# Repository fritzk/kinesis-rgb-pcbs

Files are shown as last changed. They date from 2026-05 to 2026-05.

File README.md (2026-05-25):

# PCBs to add per-key RGB lighting to Kinesis Advantage

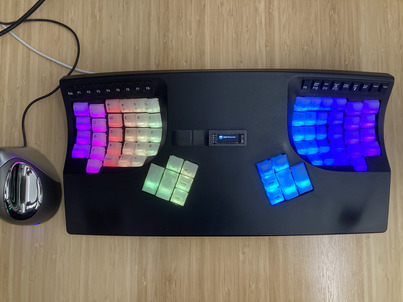
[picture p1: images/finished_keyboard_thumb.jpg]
Finished keyboard


# Attribution

Board outlines and starting schematics:

* [Pillz Mod](https://github.com/dcpedit/pillzmod) for main and thumb pcbs
* [kinesis-fn](https://github.com/bluelightning32/kinesis-fn) for function key pcbs

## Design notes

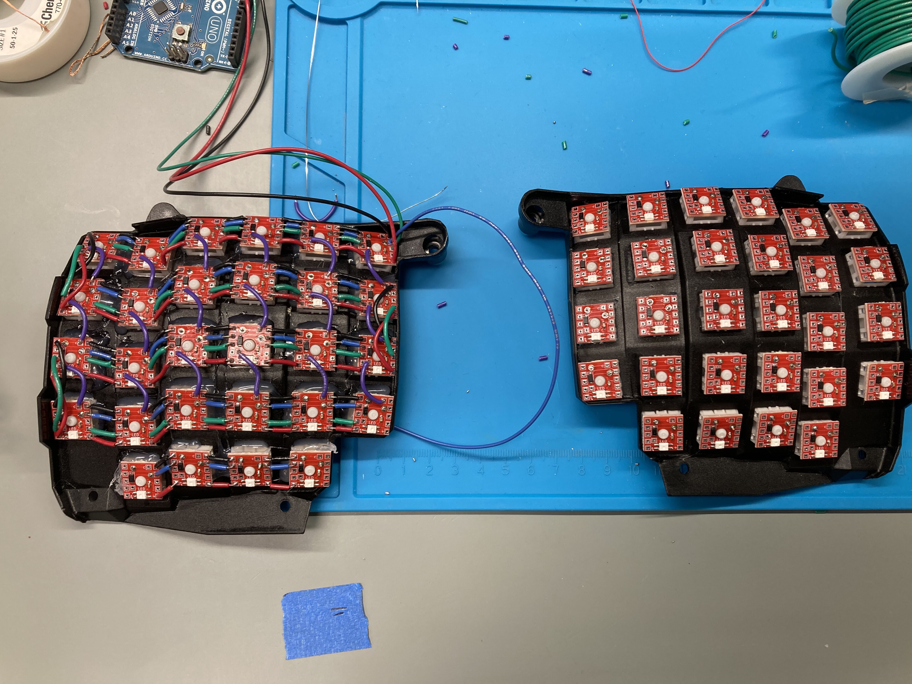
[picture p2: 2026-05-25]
key/img/key-pcb.jpg

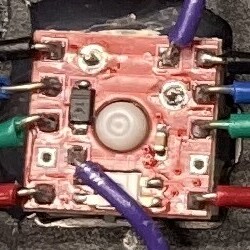
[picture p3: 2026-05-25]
key/img/key-pcb-cropped.jpg

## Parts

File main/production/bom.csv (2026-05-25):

Designator | Footprint | Quantity | Value | LCSC Part #
H1 | MountingHole_4.3mm_M4_Pad | 1 | mounting pad
J1, J2 | Molex_0039532135 | 2 | Conn_01x13
J10 | PinSocket_1x04_P2.54mm_Vertical | 1 | Conn_01x04
J3 | Molex_KK-254_AE-6410-06A_1x06_P2.54mm_Vertical | 1 | Conn_01x06
J4 | Molex_KK-254_AE-6410-06A_1x06_P2.54mm_Vertical | 1 | Conn_01x06_Pin
J5 | Molex_KK-254_AE-6410-09A_1x09_P2.54mm_Vertical | 1 | Conn_01x09
J6 | Molex_KK-254_AE-6410-09A_1x09_P2.54mm_Vertical | 1 | Conn_01x09_Pin
J7, J8 | PinHeader_1x10_P2.54mm_Vertical | 2 | Conn_01x10_Pin
J9 | PinHeader_1x01_P1.00mm_Vertical | 1 | Conn_01x01
M1 | MountingHole_6.4mm_M6 | 1 | MountingHole_6.4mm_M6
Q1 | SOT-23 | 1 | BSS138
R1, R2 | 0805 | 2 | 10K
U1 | ElitePi | 1 | Elite-Pi

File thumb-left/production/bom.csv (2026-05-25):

Designator | Footprint | Quantity | Value | LCSC Part #
C25, C35, C36, C46, C55, C56 | 0805 | 6 | 0.1 µF
D25, D35, D36, D46, D55, D56 | D_SOD-123F | 6 | 1N4148WL
J1 | PinHeader_1x10_P2.54mm_Vertical | 1 | Conn_01x10
LED25, LED35, LED36, LED46, LED55, LED56 | LED_MX_6028R | 6 | MX_SK6812MINI-E
MX25, MX35, MX55, MX56 | SW_Cherry_MX_PCB_1.00u | 4 | MX_SW_HS
MX36, MX46 | SW_Cherry_MX_PCB_2.00u_90deg | 2 | MX_SW_HS

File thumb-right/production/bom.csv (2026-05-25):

Designator | Footprint | Quantity | Value | LCSC Part #
C65, C66, C75, C85, C86, C96 | 0805 | 6 | 0.1 µF
D65, D66, D75, D85, D86, D96 | D_SOD-123F | 6 | 1N4148WL
J1 | PinHeader_1x10_P2.54mm_Vertical | 1 | Conn_01x10
LED65, LED66, LED75, LED85, LED86, LED96 | LED_MX_6028R | 6 | MX_SK6812MINI-E
MX65, MX75 | SW_Cherry_MX_PCB_2.00u_90deg | 2 | MX_SW_HS
MX66, MX85, MX86, MX96 | SW_Cherry_MX_PCB_1.00u | 4 | MX_SW_HS

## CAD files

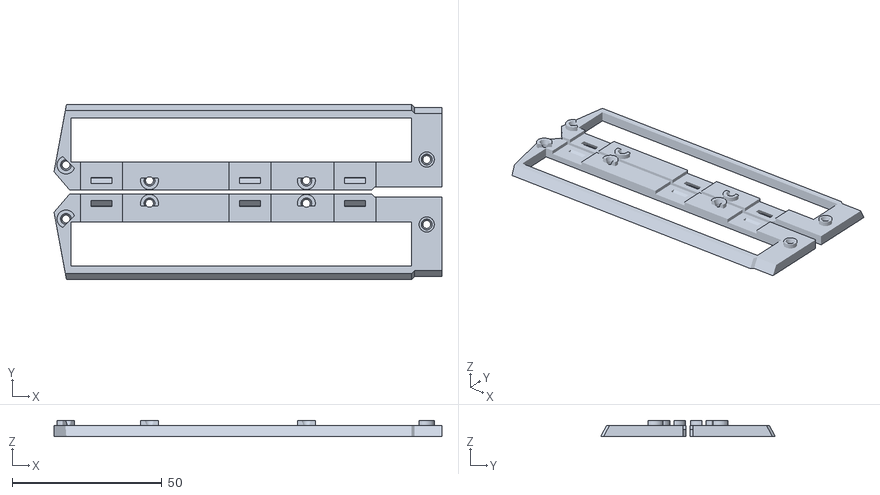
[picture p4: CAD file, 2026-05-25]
function/support.stl
129.6 x 58.4 x 5.50

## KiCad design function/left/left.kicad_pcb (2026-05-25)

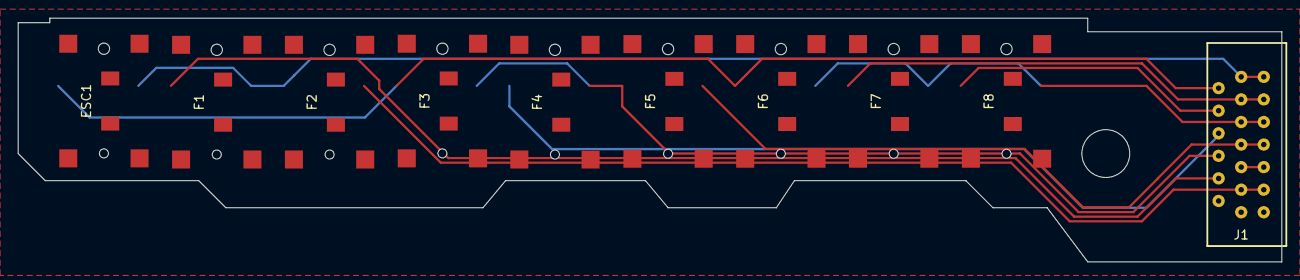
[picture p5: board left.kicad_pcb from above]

Board: 2 copper layers, 140.0 x 27.0 mm, 11 parts (0 on the bottom side), 12 nets.

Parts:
ESC1: PG1316M; SW_PG1316M
F1, F2, F3, F4, F5, F6, F7, F8: PG1316M; SW_PG1316M
H1: MountingHole_5.3mm_M5
J1: FFC_Connector_13P

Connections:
GND: J1.1, J1.1B
unnamed: ESC1.1, F3.1, F6.1, J1.12
unnamed: ESC1.2, F1.2, F2.1, J1.13, J1.13B
unnamed: F1.1, J1.4
unnamed: F2.2, J1.3, J1.3B
unnamed: F3.2, F4.2, F5.1, J1.6
unnamed: F4.1, J1.8
unnamed: F5.2, J1.7, J1.7B
unnamed: F6.2, F7.2, F8.2, J1.9, J1.9B
unnamed: F7.1, J1.11, J1.11B
unnamed: F8.1, J1.10
unnamed: J1.5, J1.5B

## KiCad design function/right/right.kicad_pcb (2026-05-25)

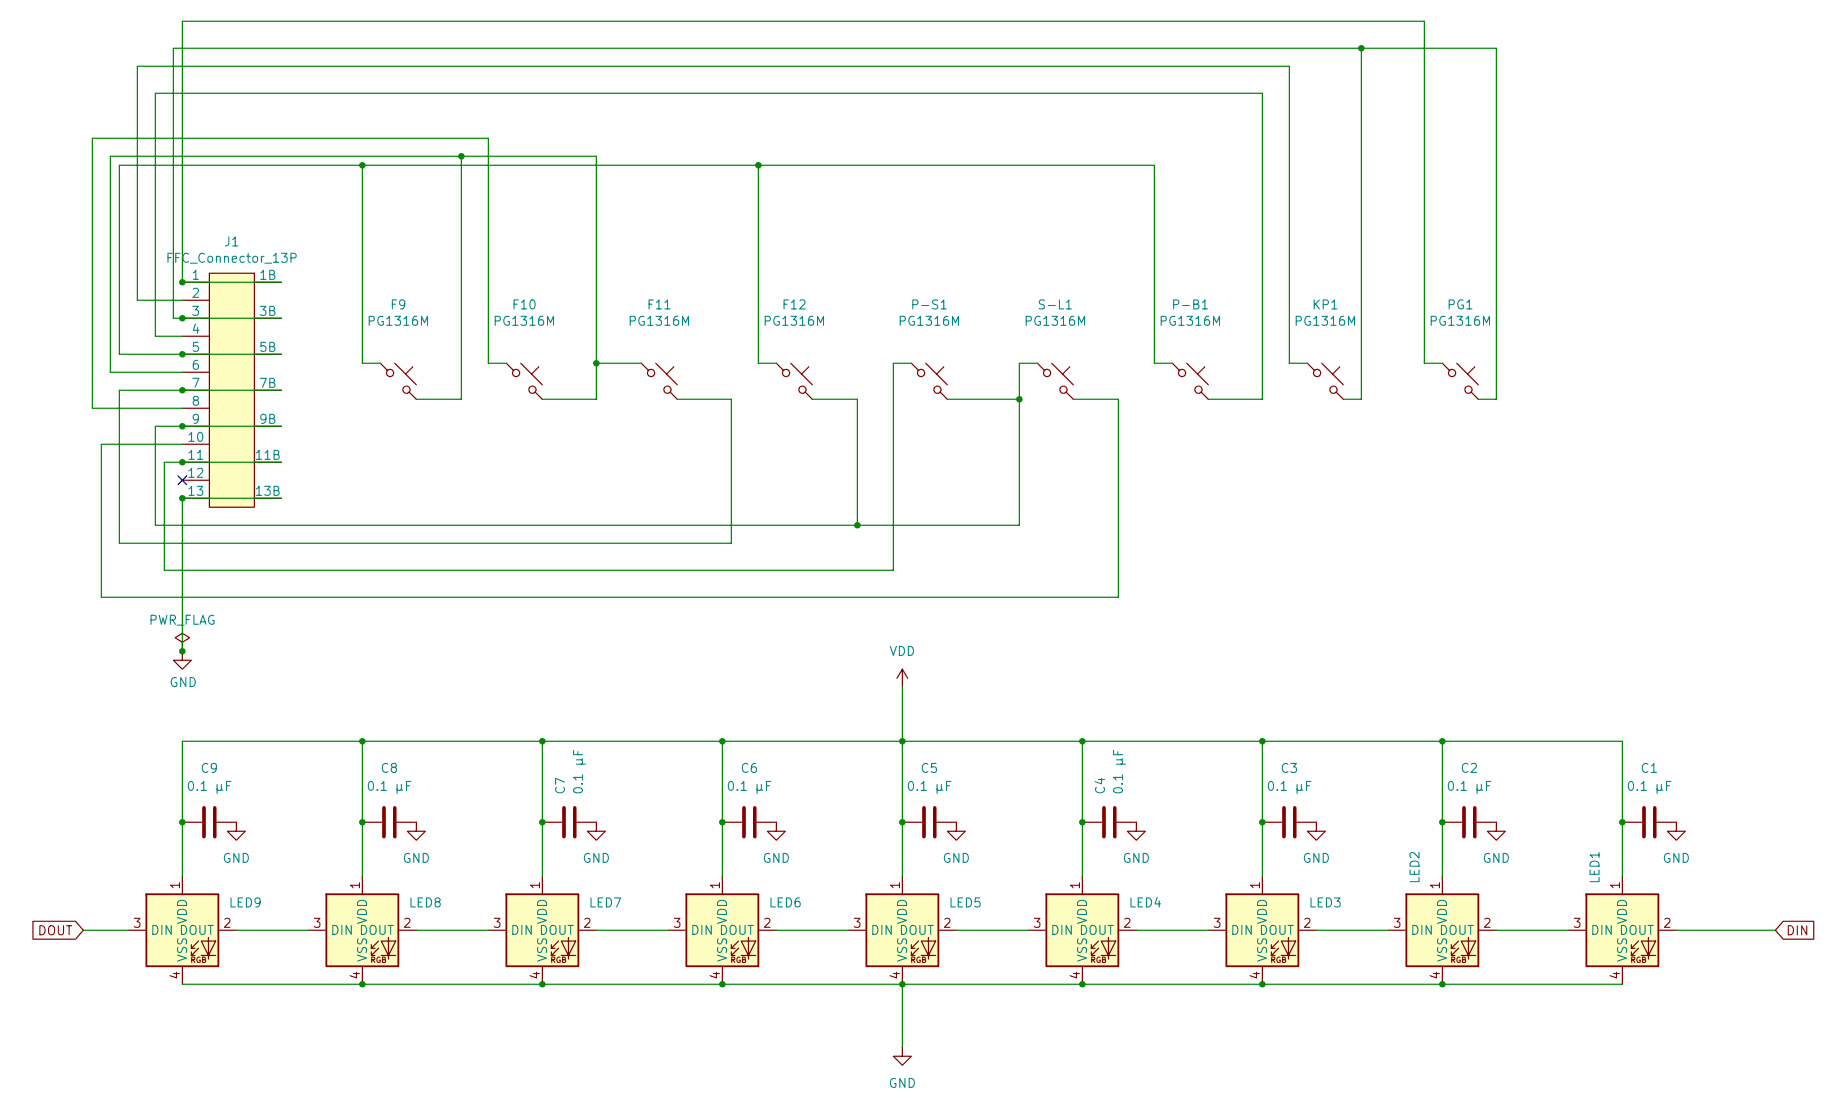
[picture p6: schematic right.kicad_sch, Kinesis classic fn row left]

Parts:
C1, C2, C3, C4, C5, C6, C7, C8, C9: 0.1 µF; C_0805_2012Metric_Pad1.18x1.45mm_HandSolder
F9, F10, F11, F12: PG1316M; SW_PG1316M
J1: FFC_Connector_13P
KP1: PG1316M; SW_PG1316M
LED1, LED2, LED3, LED4, LED5, LED6, LED7, LED8, LED9: MX_SK6812MINI-E; SK6812-MINI-E
P-B1: PG1316M; SW_PG1316M
P-S1: PG1316M; SW_PG1316M
PG1: PG1316M; SW_PG1316M
S-L1: PG1316M; SW_PG1316M

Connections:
DIN: LED1.2 (DOUT)
DOUT: LED9.3 (DIN)
GND: C1.2, C2.2, C3.2, C4.2, C5.2, C6.2, C7.2, C8.2, C9.2, J1.13, J1.13B, LED1.4 (VSS), LED2.4 (VSS), LED3.4 (VSS), LED4.4 (VSS), LED5.4 (VSS), LED6.4 (VSS), LED7.4 (VSS), LED8.4 (VSS), LED9.4 (VSS)
unnamed: F10.1, J1.8
unnamed: F9.2, F10.2, F11.1, J1.6
unnamed: F11.2, J1.7, J1.7B
unnamed: F9.1, F12.1, J1.5, J1.5B, P-B1.1
unnamed: F12.2, J1.9, J1.9B, P-S1.2, S-L1.1
unnamed: J1.1, J1.1B, PG1.1
unnamed: J1.2, KP1.1
unnamed: J1.3, J1.3B, KP1.2, PG1.2
unnamed: J1.4, P-B1.2
unnamed: J1.10, S-L1.2
unnamed: J1.11, J1.11B, P-S1.1
unnamed: LED1.3 (DIN), LED2.2 (DOUT)
unnamed: LED2.3 (DIN), LED3.2 (DOUT)
unnamed: LED3.3 (DIN), LED4.2 (DOUT)
unnamed: LED4.3 (DIN), LED5.2 (DOUT)
unnamed: LED5.3 (DIN), LED6.2 (DOUT)
unnamed: LED6.3 (DIN), LED7.2 (DOUT)
unnamed: LED7.3 (DIN), LED8.2 (DOUT)
unnamed: LED8.3 (DIN), LED9.2 (DOUT)
VDD: C1.1, C2.1, C3.1, C4.1, C5.1, C6.1, C7.1, C8.1, C9.1, LED1.1 (VDD), LED2.1 (VDD), LED3.1 (VDD), LED4.1 (VDD), LED5.1 (VDD), LED6.1 (VDD), LED7.1 (VDD), LED8.1 (VDD), LED9.1 (VDD)

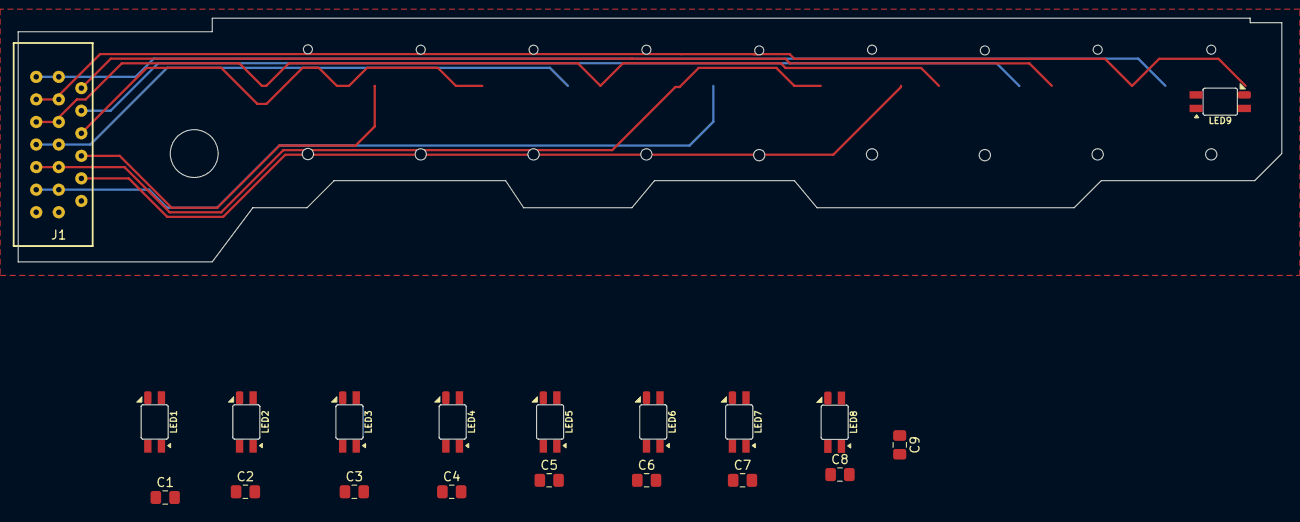
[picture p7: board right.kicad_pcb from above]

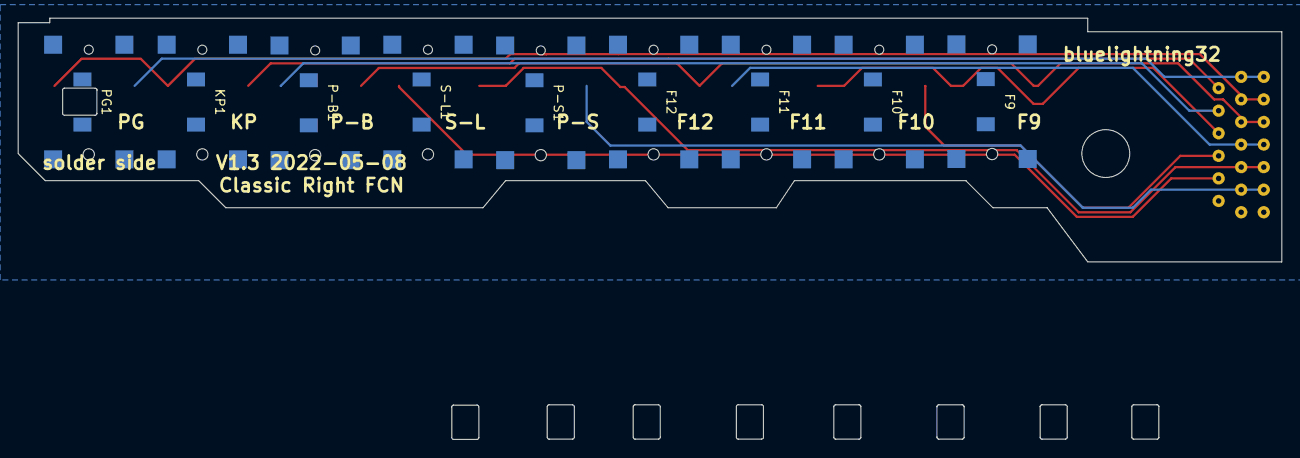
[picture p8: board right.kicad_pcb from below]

Board: 2 copper layers, 29 parts (9 on the bottom side), 21 nets.

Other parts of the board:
H1: MountingHole_5.3mm_M5

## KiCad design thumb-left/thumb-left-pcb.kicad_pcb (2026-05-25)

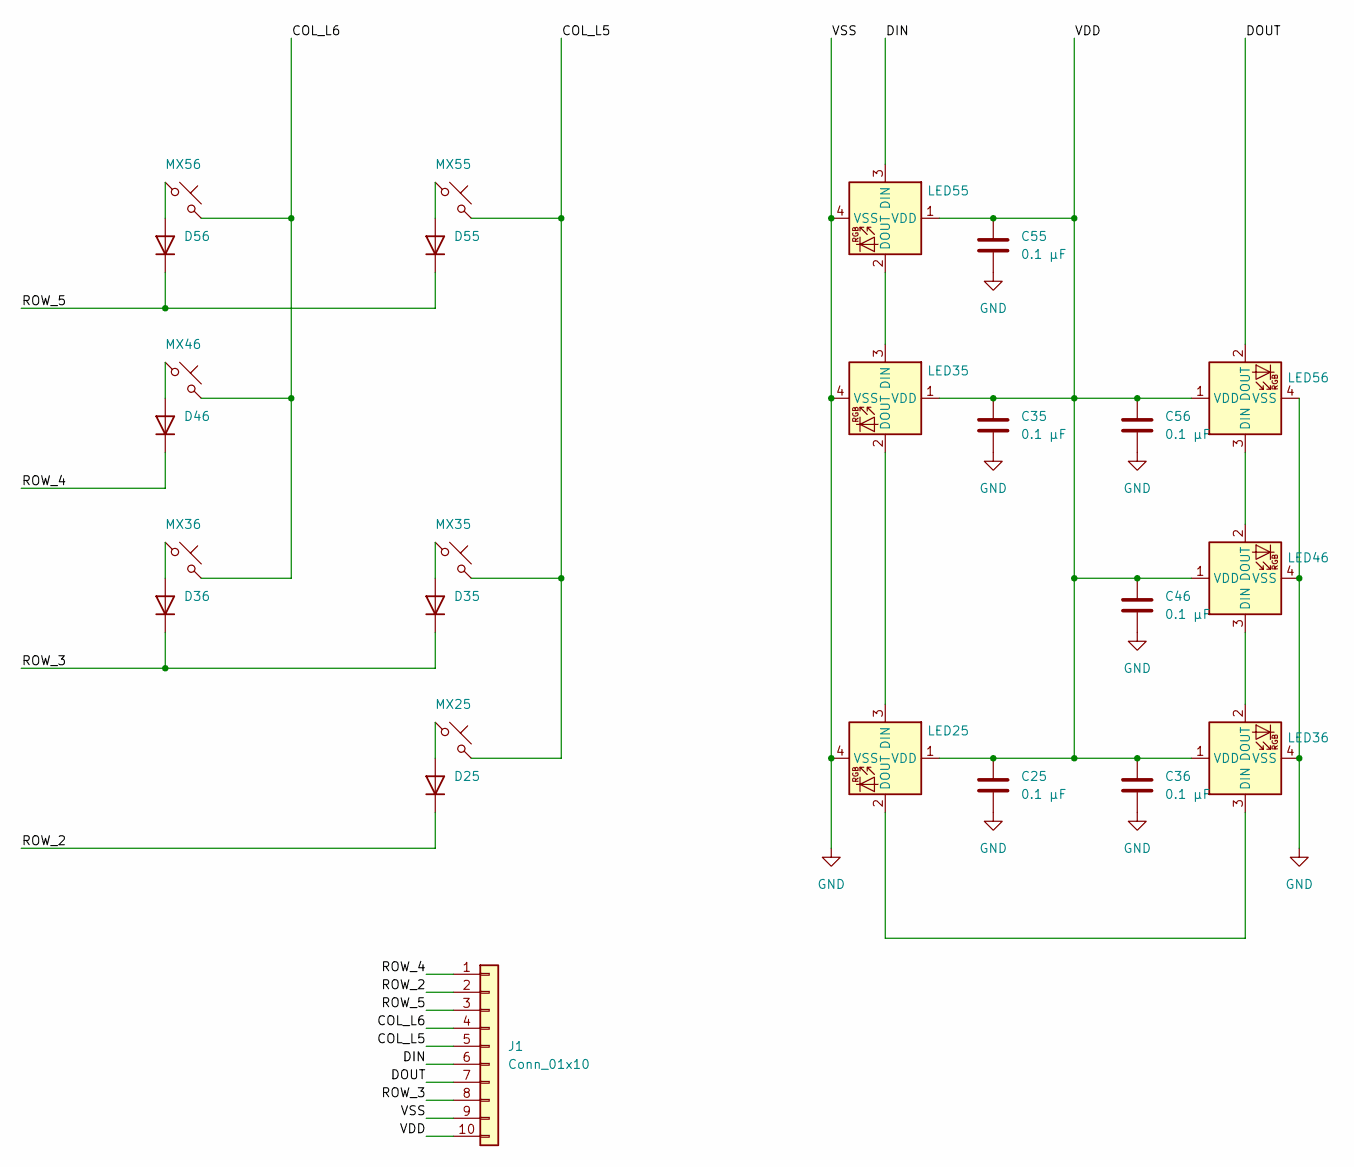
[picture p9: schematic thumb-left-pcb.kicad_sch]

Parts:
C25, C35, C36, C46, C55, C56: 0.1 µF; C_0805_2012Metric_Pad1.18x1.45mm_HandSolder
D25, D35, D36, D46, D55, D56: 1N4148WL; D_SOD-123F
J1: Conn_01x10; PinHeader_1x10_P2.54mm_Vertical
LED25, LED35, LED36, LED46, LED55, LED56: MX_SK6812MINI-E; LED_MX_6028R
MX25, MX35, MX55, MX56: MX_SW_HS; SW_Cherry_MX_PCB_1.00u
MX36, MX46: MX_SW_HS; SW_Cherry_MX_PCB_2.00u_90deg

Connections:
/COL_L5: J1.5, MX25.2, MX35.2, MX55.2
/COL_L6: J1.4, MX36.2, MX46.2, MX56.2
/DIN: J1.6, LED55.3 (DIN)
/DOUT: J1.7, LED56.2 (DOUT)
/ROW_2: D25.1 (K), J1.2
/ROW_3: D35.1 (K), D36.1 (K), J1.8
/ROW_4: D46.1 (K), J1.1
/ROW_5: D55.1 (K), D56.1 (K), J1.3
/VDD: C25.1, C35.1, C36.1, C46.1, C55.1, C56.1, J1.10, LED25.1 (VDD), LED35.1 (VDD), LED36.1 (VDD), LED46.1 (VDD), LED55.1 (VDD), LED56.1 (VDD)
GND: C25.2, C35.2, C36.2, C46.2, C55.2, C56.2, J1.9, LED25.4 (VSS), LED35.4 (VSS), LED36.4 (VSS), LED46.4 (VSS), LED55.4 (VSS), LED56.4 (VSS)
unnamed: D25.2 (A), MX25.1
unnamed: D35.2 (A), MX35.1
unnamed: D36.2 (A), MX36.1
unnamed: D46.2 (A), MX46.1
unnamed: D55.2 (A), MX55.1
unnamed: D56.2 (A), MX56.1
unnamed: LED25.3 (DIN), LED35.2 (DOUT)
unnamed: LED25.2 (DOUT), LED36.3 (DIN)
unnamed: LED35.3 (DIN), LED55.2 (DOUT)
unnamed: LED36.2 (DOUT), LED46.3 (DIN)
unnamed: LED46.2 (DOUT), LED56.3 (DIN)

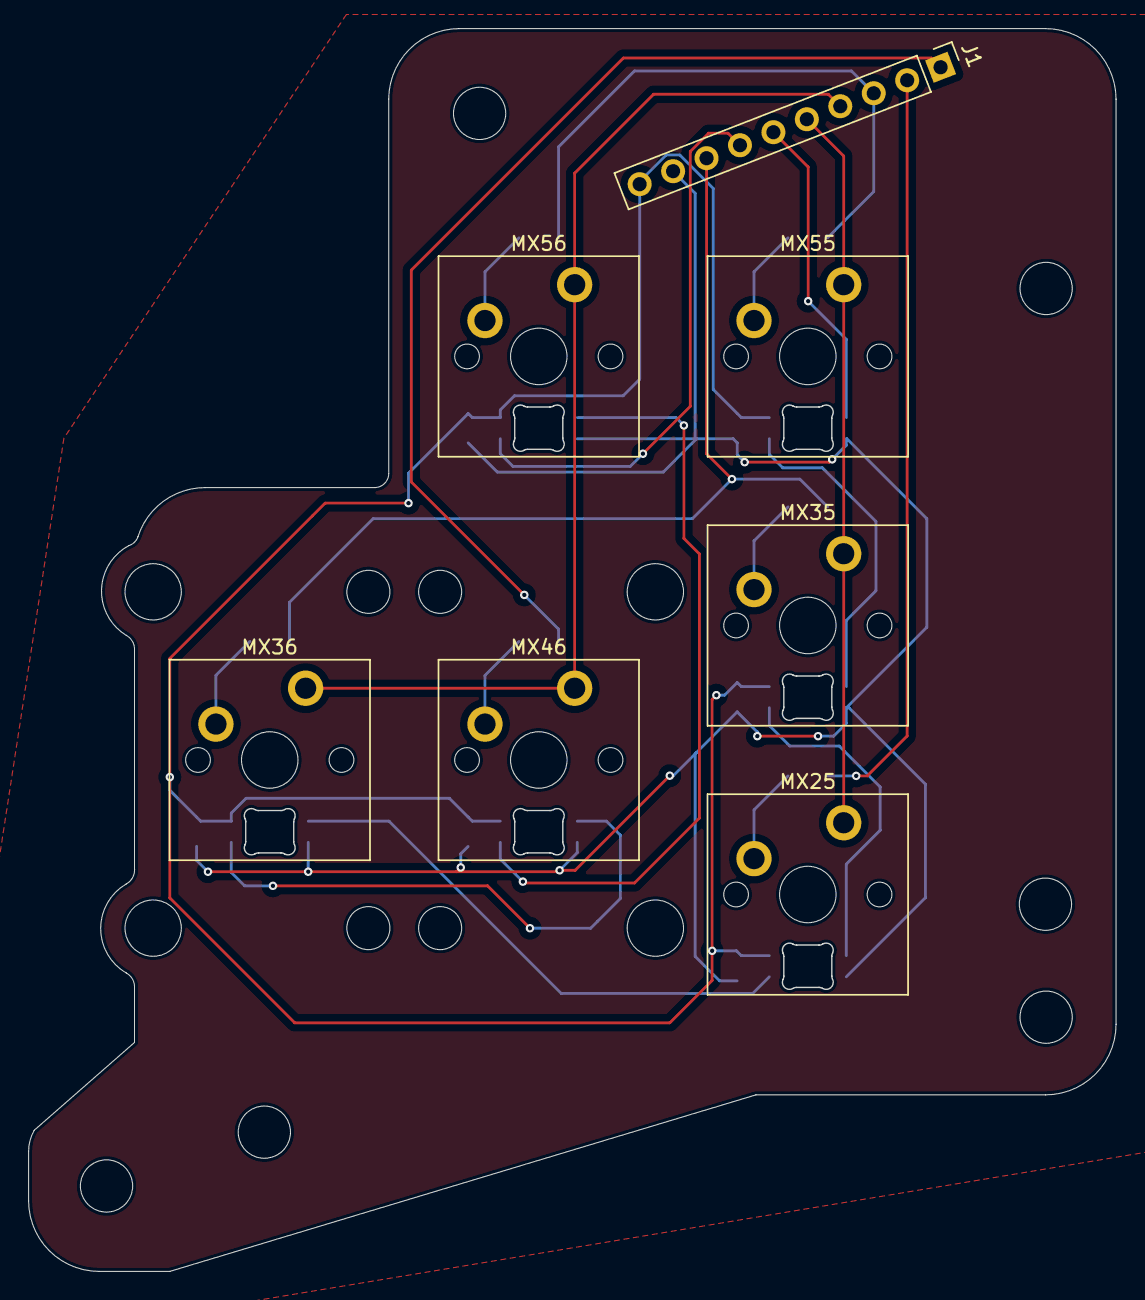
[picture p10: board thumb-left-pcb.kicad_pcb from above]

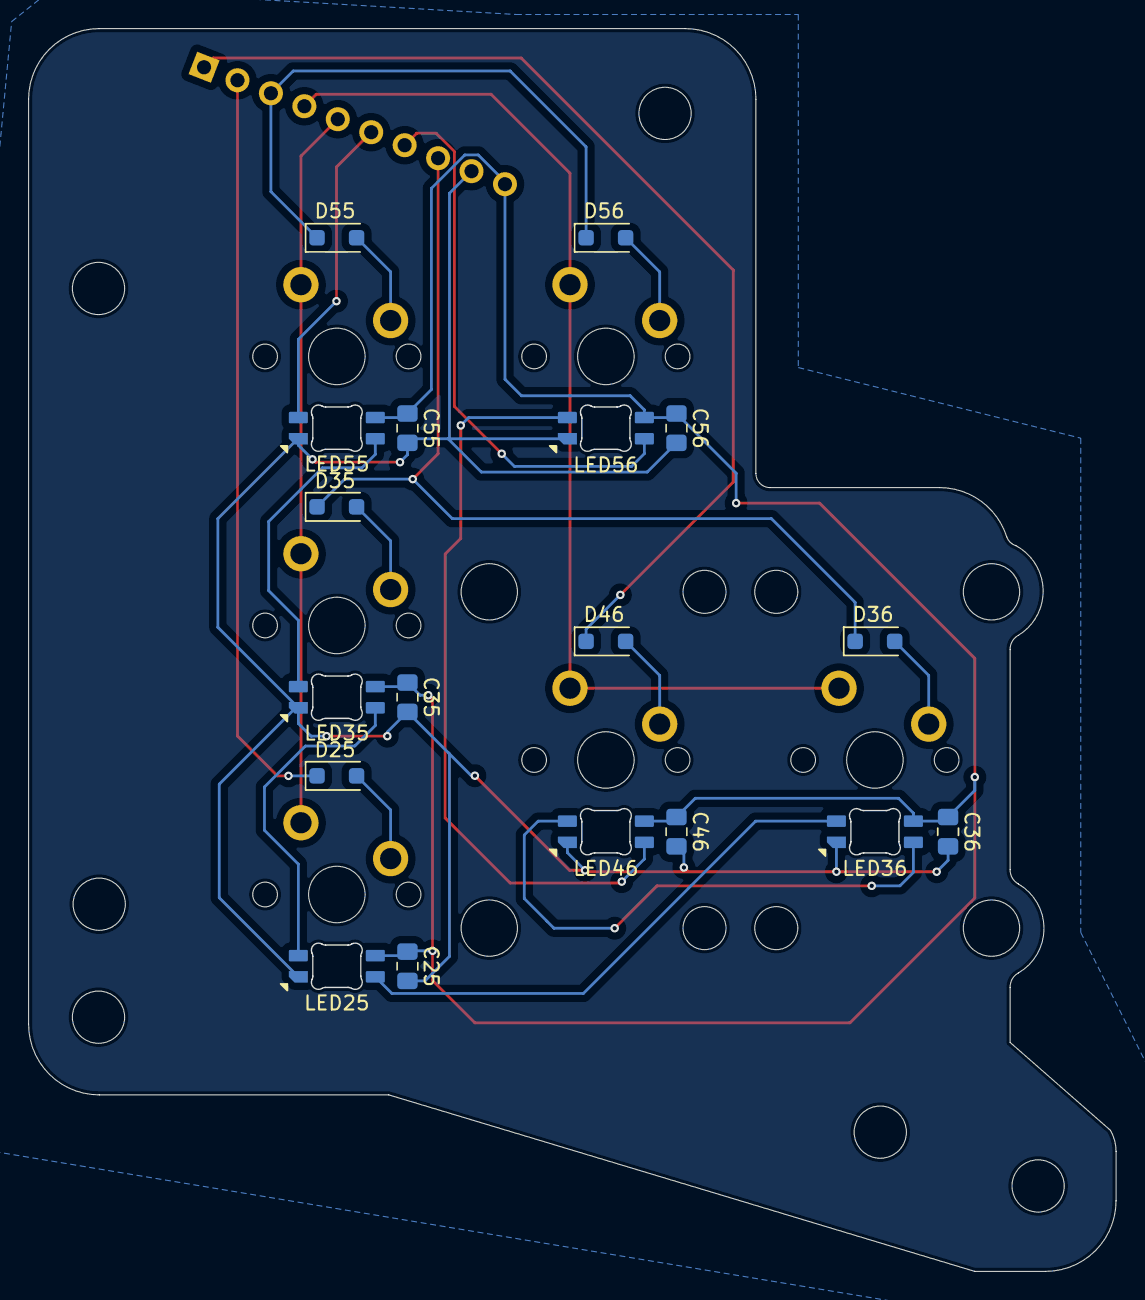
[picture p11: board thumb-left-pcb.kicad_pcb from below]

Board: 2 copper layers, 77.0 x 88.0 mm, 31 parts (18 on the bottom side), 21 nets.

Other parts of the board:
REF1, REF2, REF3, REF4, REF5, REF6: MountingHole_3.7mm

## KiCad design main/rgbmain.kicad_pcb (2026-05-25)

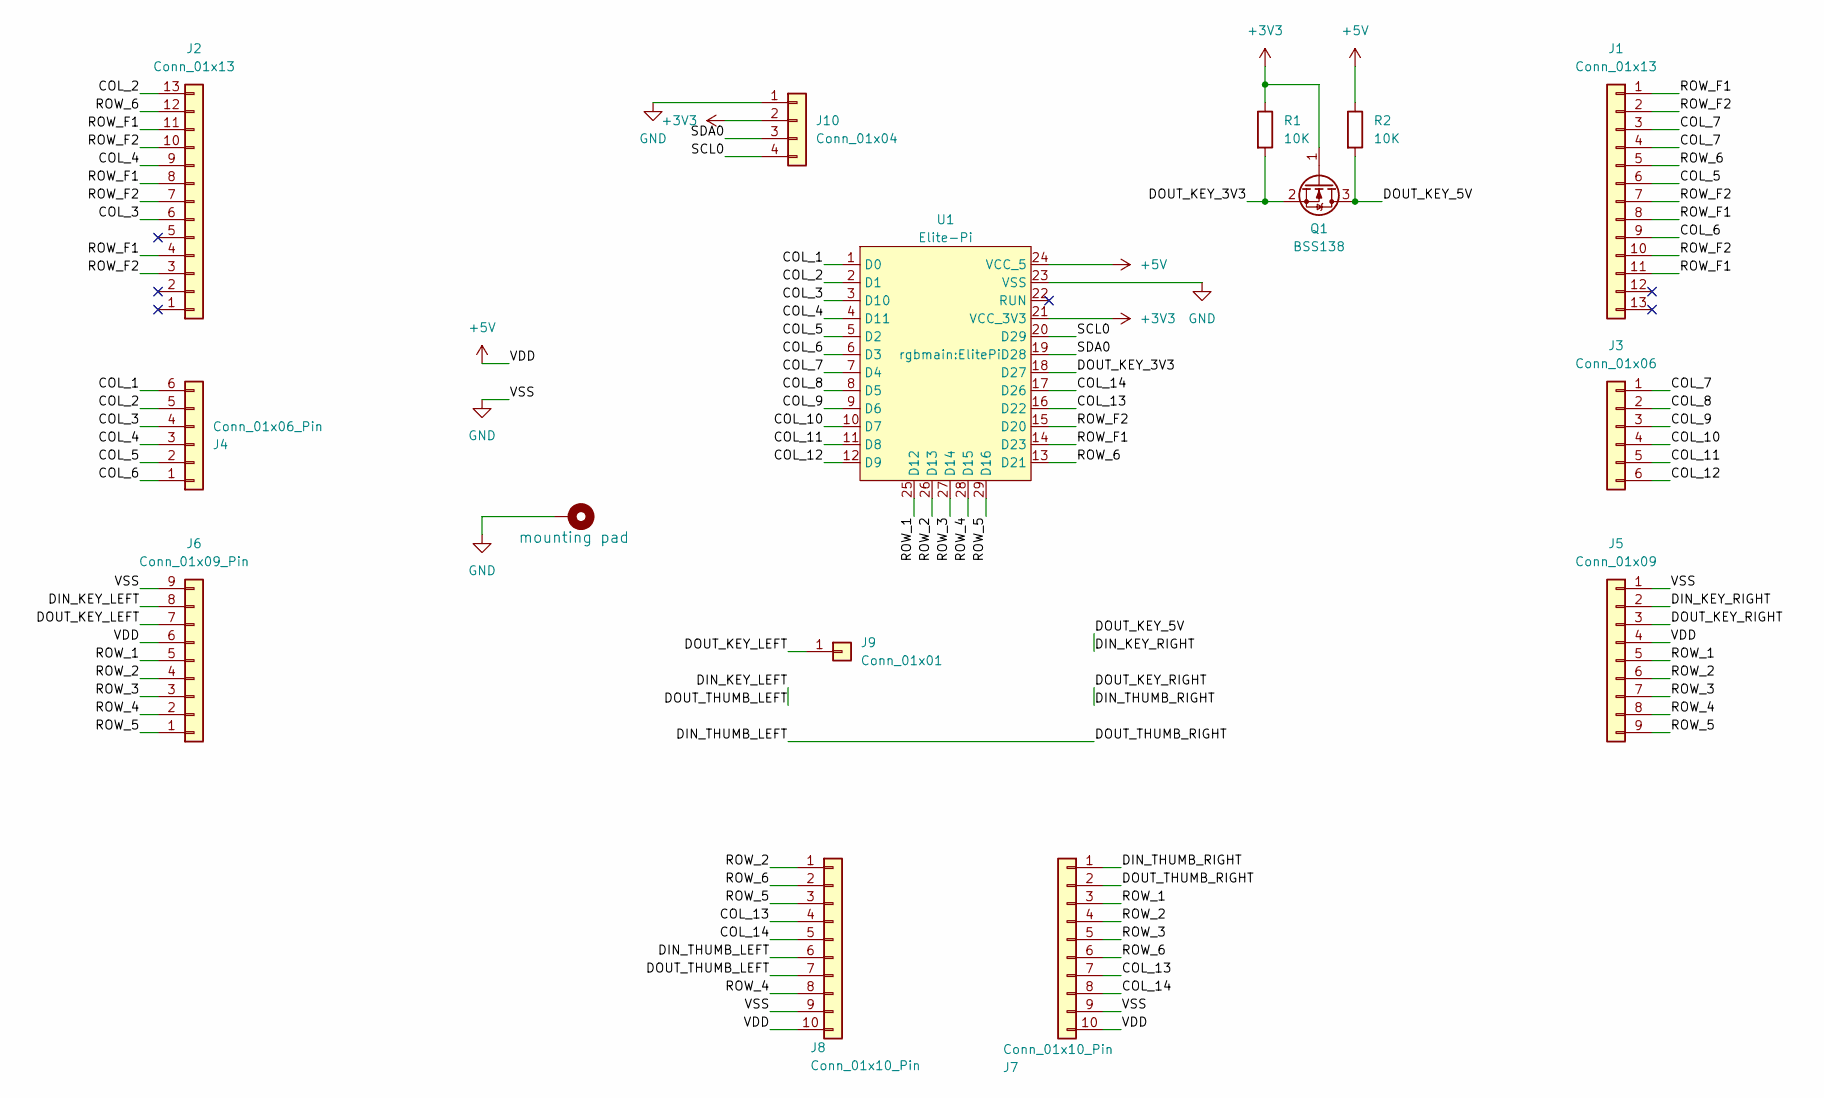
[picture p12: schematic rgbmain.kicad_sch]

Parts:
H1: mounting pad; MountingHole_4.3mm_M4_Pad
J1, J2: Conn_01x13; Molex_0039532135
J3: Conn_01x06; Molex_KK-254_AE-6410-06A_1x06_P2.54mm_Vertical
J4: Conn_01x06_Pin; Molex_KK-254_AE-6410-06A_1x06_P2.54mm_Vertical
J5: Conn_01x09; Molex_KK-254_AE-6410-09A_1x09_P2.54mm_Vertical
J6: Conn_01x09_Pin; Molex_KK-254_AE-6410-09A_1x09_P2.54mm_Vertical
J7, J8: Conn_01x10_Pin; PinHeader_1x10_P2.54mm_Vertical
J9: Conn_01x01; PinHeader_1x01_P1.00mm_Vertical
J10: Conn_01x04; PinSocket_1x04_P2.54mm_Vertical
Q1: BSS138; SOT-23
R1, R2: 10K; R_0805_2012Metric_Pad1.20x1.40mm_HandSolder
U1: Elite-Pi; ElitePi

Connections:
+3V3: J10.2, Q1.1 (G), R1.1, U1.21 (VCC_3V3)
+5V: J5.4, J6.6, J7.10, J8.10, R2.1, U1.24 (VCC_5)
/COL_1: J4.6, U1.1 (D0)
/COL_2: J2.13, J4.5, U1.2 (D1)
/COL_3: J2.6, J4.4, U1.3 (D10)
/COL_4: J2.9, J4.3, U1.4 (D11)
/COL_5: J1.6, J4.2, U1.5 (D2)
/COL_6: J1.9, J4.1, U1.6 (D3)
/COL_7: J1.3, J1.4, J3.1, U1.7 (D4)
/COL_8: J3.2, U1.8 (D5)
/COL_9: J3.3, U1.9 (D6)
/COL_10: J3.4, U1.10 (D7)
/COL_11: J3.5, U1.11 (D8)
/COL_12: J3.6, U1.12 (D9)
/COL_13: J7.7, J8.4, U1.16 (D22)
/COL_14: J7.8, J8.5, U1.17 (D26)
/DIN_KEY_LEFT: J6.8, J8.7
/DIN_KEY_RIGHT: J5.2, Q1.3 (D), R2.2
/DIN_THUMB_LEFT: J7.2, J8.6
/DIN_THUMB_RIGHT: J5.3, J7.1
/DOUT_KEY_3V3: Q1.2 (S), R1.2, U1.18 (D27)
/DOUT_KEY_LEFT: J6.7, J9.1
/ROW_1: J5.5, J6.5, J7.3, U1.25 (D12)
/ROW_2: J5.6, J6.4, J7.4, J8.1, U1.26 (D13)
/ROW_3: J5.7, J6.3, J7.5, U1.27 (D14)
/ROW_4: J5.8, J6.2, J8.8, U1.28 (D15)
/ROW_5: J5.9, J6.1, J8.3, U1.29 (D16)
/ROW_6: J1.5, J2.12, J7.6, J8.2, U1.13 (D21)
/ROW_F1: J1.1, J1.8, J1.11, J2.4, J2.8, J2.11, U1.14 (D23)
/ROW_F2: J1.2, J1.7, J1.10, J2.3, J2.7, J2.10, U1.15 (D20)
/SCL0: J10.4, U1.20 (D29)
/SDA0: J10.3, U1.19 (D28)
GND: H1.1, J5.1, J6.9, J7.9, J8.9, J10.1, U1.23 (VSS)

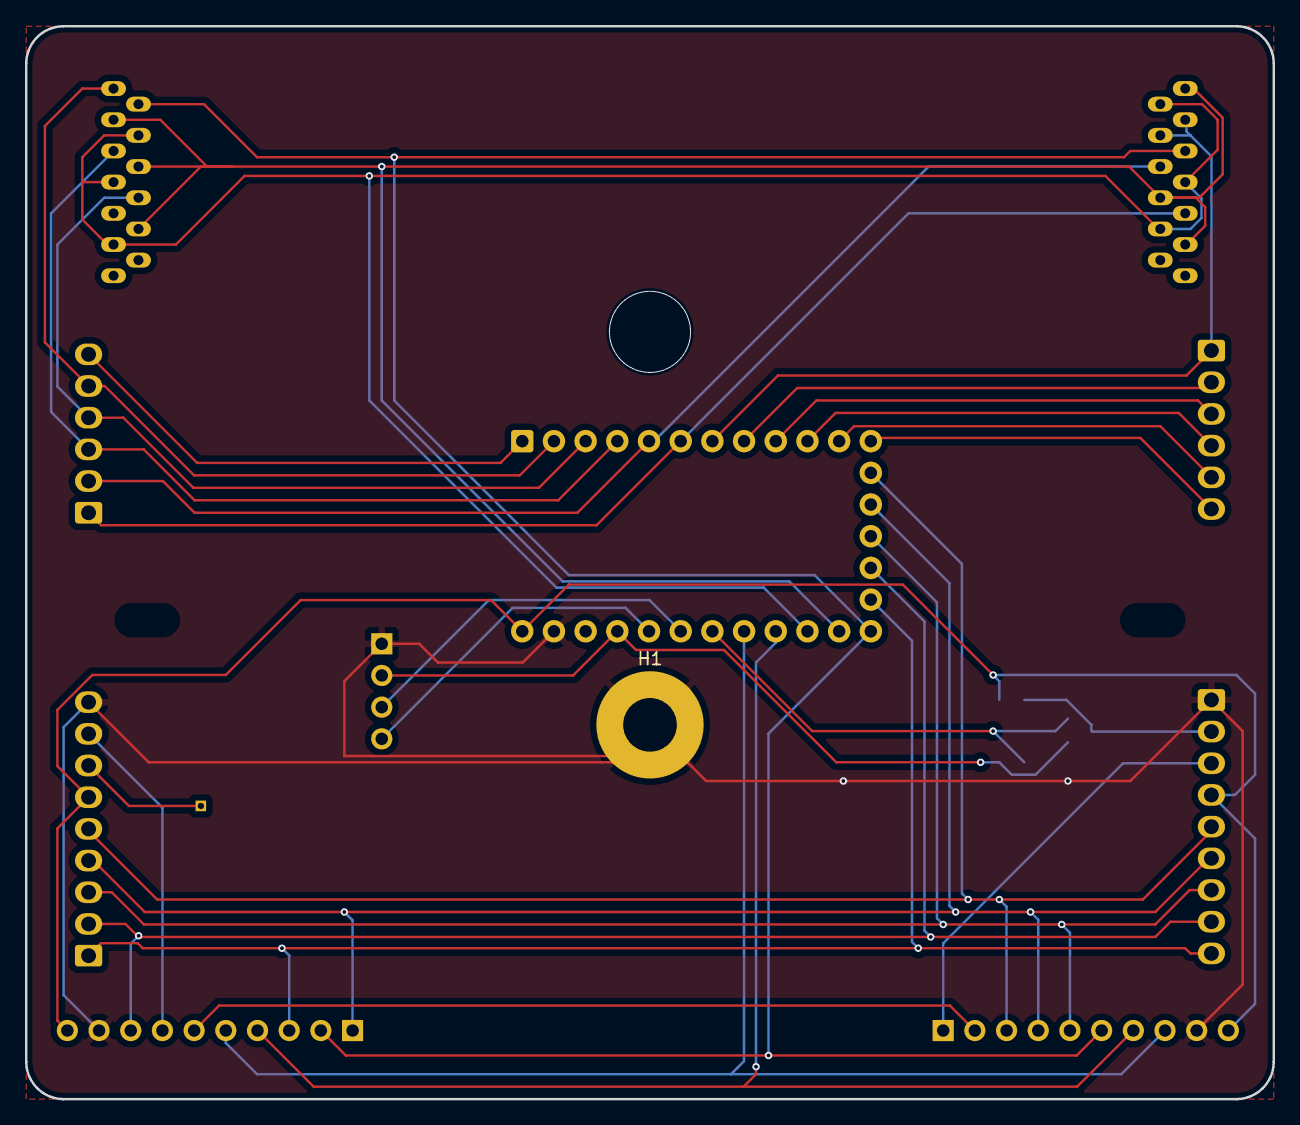
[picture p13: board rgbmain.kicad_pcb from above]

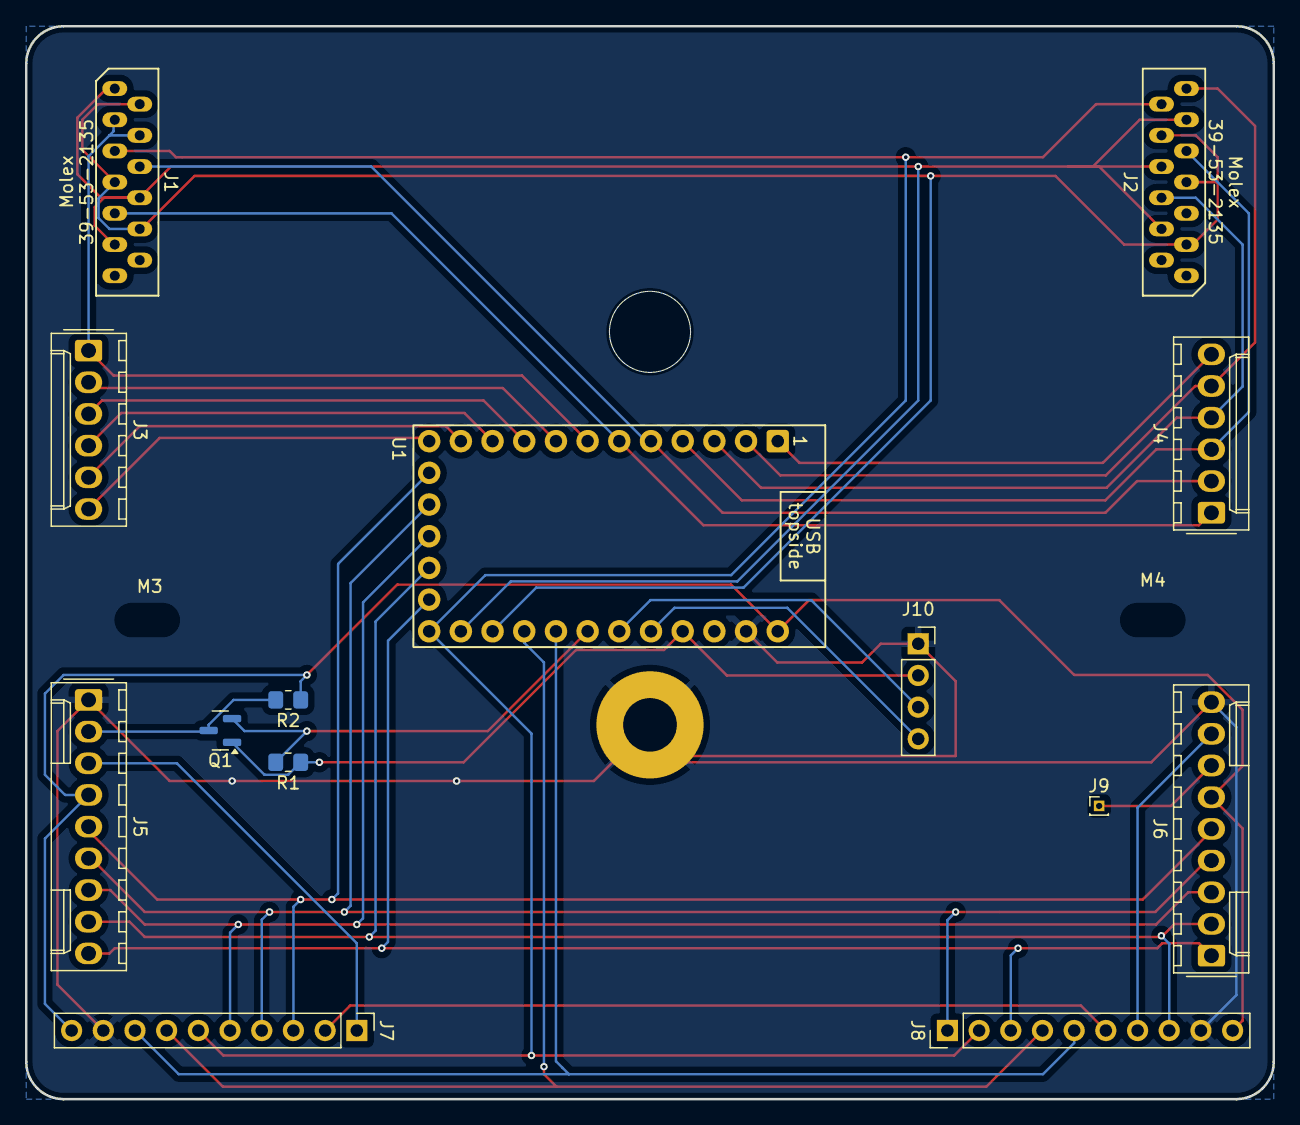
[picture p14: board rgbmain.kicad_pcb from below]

Board: 2 copper layers, 100.0 x 86.0 mm, 18 parts (17 on the bottom side), 33 nets.

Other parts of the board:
M1: MountingHole_6.4mm_M6
M3, M4: MountingHole_4.3mm_M4

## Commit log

2026-05-25 import kinesis function keys
    from https://github.com/bluelightning32/kinesis-fn
    [left-B_Cu.gbl, left-B_Mask.gbs, left-B_SilkS.gbo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]
2026-05-25 cleanup import
    [left-B_Cu.gbl, left-B_Mask.gbs, left-B_SilkS.gbo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]
2026-05-25 drop -pcb from directory names
    [bom.csv, designators.csv, key-pcb.kicad_pcb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]
2026-05-25 rgb switches
    convert to KiCad 9 (move directories)
    pg1316m switches
    sk6812mini-e lights
    [left.kicad_pcb, left.kicad_sch, left.sch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]
2026-05-25 drop Pillz Mod thumb cluster
    was used as reference
    [kinesis-thumb-pcb.kicad_pcb, kinesis-thumb-pcb.kicad_sch, kinesis-thumb-pcb.sch]

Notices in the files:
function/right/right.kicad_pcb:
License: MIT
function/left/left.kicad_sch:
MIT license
